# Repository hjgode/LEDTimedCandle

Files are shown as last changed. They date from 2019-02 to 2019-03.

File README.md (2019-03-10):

# LEDTimedCandle

I did a lot of research on battery powered LED candle lights circuits and code and was unable to find a time controlled LED candle light.

As I have some ATTiny13 left, I decided to use this little chip. As I want the LED to do a candle light for about 4hours and then stay of for another 20 hours, I need on timer and counter. Another timer/PWM is needed to immitate a candle flickering. But the ATTiny13 has only one timer. On the ATTiny13 you can either use the timer or PWM.

Fortunately the ATTiny has also a Watchdog timer that can be used to call an interrupt function. The watchdog runs with a separate 128kHz clock, independent from the CPU clock. The largest timeout is 8 seconds. So I need to count this 450 times to have one hour.

Update:
The 128KHz Oscillator for wdt is in real a 131072Hz oscillator (mixing k=1000 and k=1024!).
The ATTiny13A Data sheet says wdt osc will run at 113000Hz at 2V/20°C:

    1024k cycles are 1048576 cycles
    so:
    113000 / 1048576 = 0.1077 => 9.285 seconds
    131072 / 1048576 = 0.125  => 8     seconds
    for one hour we get:
    450*8    = 3600    = 60    minutes
    450*9.285= 4178.27 = 69.63 minutes
    the error cumulates to
    4h 60*4    = 240 
       69.63*4 = 278.55
    diff is 38.55 minutes! in 4 hours
    for 24 hours:
    24h @ 8seconds = 1440
        @ 9.285sec = 1671.12
    diff is 231 minutes for a day! this is 3.85 hours (3h51m) a day!

Instead of theoratic 450 cycles of 8seconds for an hour:
    60*60/9.285=387.72
I now use 388 cycles.

The code makes the ATTiny13 sleep for another 8 seconds or light the LED. The ON phase is 4 hours and the sleep phase will be extended to 20 hours. The sequence starts with the ON phase, when power is applied. In the ON phase I measure about 3mA and in the OFF phase the circuit needs 3µA (without my ISP programmer attached :-).

The circuit is documented in the Arduino code file. Running the ATTiny13 at lower clock than 9.6MHz did not change the power usage. But I switched to the 1.2MHz internal clock and disabled BOD (auto power down for low power) to get a longer runtime with two or three AA batteries.

# References:
* 8.4 Watchdog timer, page 38 ->says 128kHz but means 131072 Hz (kilo for Hertz is 1000 and not 1024 normally)
* watchdog timer prescaler table 8-2, page 43
* Figure 19-65. 128 kHz Watchdog Oscillator Frequency vs. VCC, page 157 ->shows wdt frequency from 105000 to 115000, where is the 128kHz (131072Hz)?

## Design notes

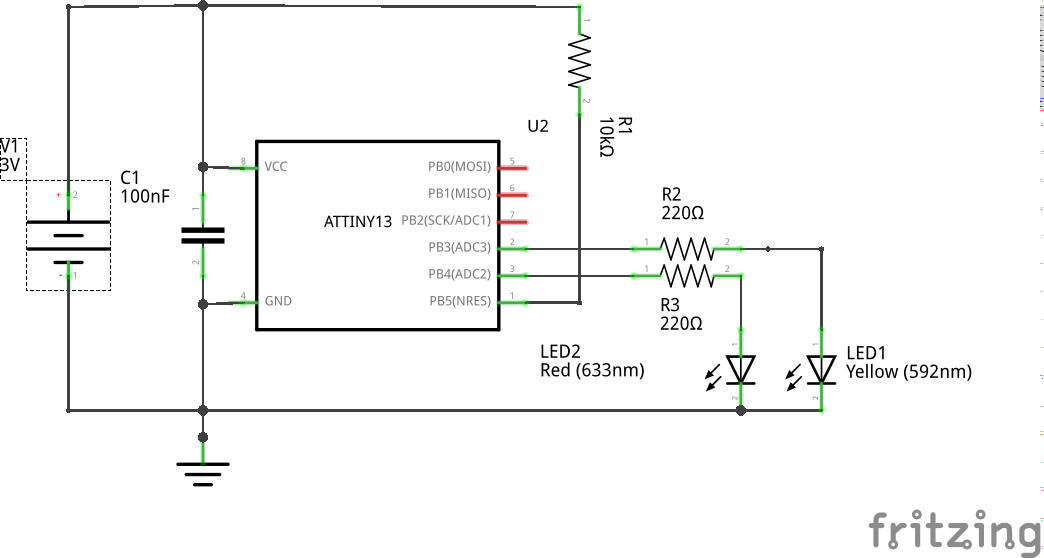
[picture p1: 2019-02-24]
doc/LEDTimedCandle_schem.png

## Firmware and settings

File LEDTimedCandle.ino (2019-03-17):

//use for debug to speed up cycles
//#define MY_DEBUG

//you may need to disable millis in packages/MicroCore/hardware/avr/1.0.4/cores/microcore/core_settings.h

//default 9.6MHz / 8 = 1200000 or at 4.8MHz / 8 = 600000
//use 1.2MHz then 150000, 1200000L
#ifndef F_CPU
	#define F_CPU 1200000L
#endif

// ATtiny13 candle with long sleep mode, wake watchdog timer
// microCore: https://github.com/MCUdude/MicroCore
// Date: 12 October 2013

// http://forum.arduino.cc/index.php?topic=200590.0
// https://electronics.stackexchange.com/questions/74840/use-avr-watchdog-like-normal-isr

// ATMEL ATTINY 13 / ARDUINO
//
// ######### NOTES ########
// disable BOD
// set CPU clock to 1.2MHz should run OK with 1.8V
// ########################

//                      +-\/-+
// RST Ain0 (D 5) PB5  1|    |8  Vcc
//     Ain3 (D 3) PB3  2|    |7  PB2 (D 2) Ain1 SCK
//     Ain2 (D 4) PB4  3|    |6  PB1 (D 1) pwm1 MISO
//                GND  4|    |5  PB0 (D 0) pwm0 MOSI
//                      +----+

//                  +-------------+--o VCC
//                  |             |
//    47k          | |            |    
//                 | |            |
//                  |   +-\/-+    |
//             LED  +--1|    |8---+
//    LED    +--|<-----2|    |7   |                
//           |         3|    |6   |
//    100   | |    +---4|    |5   |
//          | |    |    +----+   ===
//           |     |             === 220pF
//           |     |              |
//          ---   ---            ---
//
// option: add LED on pin 3 (PB4) for heart beat every WDT interrupt

/* ISP 6pol
              +--------+
      MISO    |  o  o  |    VTG (VCC)
              ++       |
      SCK      | o  o  |    MOSI
              ++       |
      RST     |  o  o  |    GND
              +--------+
*/

#include <avr/interrupt.h>
#include <avr/sleep.h>    // Sleep Modes
#include <avr/power.h>    // Power management
#include <avr/wdt.h>      // Watchdog timer
#include <avr/io.h>
#include <util/delay.h>

#ifdef USE_I2C
    #include "./i2c/i2c.h"
#endif
#ifdef USE_I2CMASTER
    #include "./i2cmaster/i2cmaster.h"
#endif

#ifndef WDIF
  #define WDIF WDTIF
#endif
#ifndef WDIE
  #define WDIE WDTIE
#endif
#ifndef bit
    #define bit(b) (1UL << (b))
    //#define _BV(b) (1UL << (b))
#endif

#define USE_HEART_BEAT_LED

//for 8seconds 450 times will be one hour
//but in real we have 113000Hz instead of 131072, the time drifts 3h51m for a day!
//we have two intervals: on-time=4hours; off-time=20 hours
volatile uint16_t sec8_counter=0;
#ifndef MY_DEBUG
  //450x8 = 3600 seconds = 60 minutes
  #define HOUR_INTERVAL 388
  //450
  #define MAX_OFF_HOURS 20
  #define MAX_ON_HOURS 4
#else
  //DEBUG: 1x8 = 8 seconds : ON time = 8x2, OFF time=8*2 seconds
  #define HOUR_INTERVAL 1
  #define MAX_OFF_HOURS 2
  #define MAX_ON_HOURS 2
#endif
volatile uint8_t  on_hours=0;

volatile uint8_t  off_hours=0;
volatile uint8_t bLedIsOn=1; //we start in ON mode

#define LED 3 //;  // pin 2, PB3
#ifdef USE_HEART_BEAT_LED
#define LED2 4 //; // pin 3 for heart beat LED, PB4
#endif

//for candle simulation via pwm
uint8_t PWM_CTR=0;    // 4 bit-Counter
uint8_t FRAME_CTR=0;  // 5 bit-Counter

uint8_t PWM_VAL=0;    // 4 bit-Register
uint8_t NEXTBRIGHT=0; // 4 bit-Register
uint8_t RAND=0;     // 5 bit Signal
uint8_t randflag=0;   // 1 bit Signal

/*
  32 Bit maximum length LFSR
  see http://www.ece.cmu.edu/~koopman/lfsr/index.html
  
  Using inverted values so the LFSR also works with zero initialisiation.
  
*/
uint8_t Rand(void) {
  static uint32_t Z;
  
    if (Z & 1)  { Z = (Z >> 1); }
    else        { Z = (Z >> 1) ^ 0x7FFFF159; }
  
  return (uint8_t)Z;
}

// watchdog interrupt
ISR (WDT_vect)
{
  sec8_counter++;

#ifdef USE_HEART_BEAT_LED  
  //flash heart beat LED
  //turns B0 HIGH
  PORTB |=(1<<LED2);//  digitalWrite(LED2, HIGH);
  _delay_ms(1);
  //turns LED2 LOW
  PORTB &= ~(1 << LED2);//  digitalWrite(LED2, LOW);
#endif
  
  if(sec8_counter>=HOUR_INTERVAL){
    sec8_counter=0;
    if(bLedIsOn==1){
      on_hours++;
      if(on_hours>=MAX_ON_HOURS){
        bLedIsOn=0; //switch to OFF mode
        off_hours=0;
      }
    }else{
      off_hours++;
      if(off_hours>=MAX_OFF_HOURS){
        bLedIsOn=1; //switch to ON mode
        on_hours=0;
      }
    }
  }
  wdt_reset();
}  // end of WDT_vect

void resetWatchdog (void)
{
  // clear various "reset" flags
  MCUSR = 0;    
  // allow changes, disable reset, clear existing interrupt
  WDTCR = bit (WDCE) | bit (WDE) | bit (WDIF);
  // set interrupt mode and an interval (WDE must be changed from 1 to 0 here)
  ///WDTCR = bit (WDIE) | bit (WDP2) | bit (WDP1) | bit (WDP0);    // set WDIE, and 2 seconds delay
#ifdef MY_DEBUG
  WDTCR = bit (WDIE) | bit (WDP2) | bit (WDP1);    // set WDIE, and 1 seconds delay
#else
  WDTCR = bit (WDIE) | bit (WDP3) | bit (WDP0);    // set WDIE, and 8 seconds delay
#endif
  // pat the dog
  wdt_reset();  
}  // end of resetWatchdog
 

 
void goToSleep(void)
{
  set_sleep_mode (SLEEP_MODE_PWR_DOWN);
  ADCSRA = 0;            // turn off ADC
  power_all_disable ();  // power off ADC, Timer 0 and 1, serial interface
  //set all unused ports to output, uses another 8 bytes
/*  
  pinMode(0, OUTPUT);
  pinMode(1, OUTPUT);
  pinMode(2, OUTPUT);
  PORTB = 0b000000; //all low
*/
  cli(); //noInterrupts ();       // timed sequence coming up
  resetWatchdog ();      // get watchdog ready
  sleep_enable ();       // ready to sleep
  sei(); //interrupts ();         // interrupts are required now
  sleep_cpu ();        // sleep                
  sleep_disable ();      // precaution
  power_all_enable();//power_all_enable ();   // power everything back on
}  // end of goToSleep



//mimic candle: https://github.com/cpldcpu/CandleLEDhack/blob/master/Emulator/CandeflickerLED.c
void doCandle(void)
{
if(F_CPU==150000){
  _delay_us(1e6/440/16);
}
if(F_CPU==1200000L){
  _delay_us(1e6/440/16*8);   // Main clock=440*16 Hz
}
  // PWM    
  PWM_CTR++;
  PWM_CTR&=0xf;   // only 4 bit
  
  if (PWM_CTR<=PWM_VAL) {
      //turns B0 HIGH
     PORTB |=(1<<LED);//digitalWrite (LED, HIGH);
  } else {
    //turns B3 LOW
    PORTB &= ~(1 << LED);//digitalWrite (LED, LOW);
  }
  // FRAME
  if (PWM_CTR==0) 
  {
    FRAME_CTR++;
    FRAME_CTR&=0x1f;
    
    if ((FRAME_CTR&0x07)==0)  // generate a new random number every 8 cycles. In reality this is most likely bit serial
    {
      RAND=Rand()&0x1f;
      randflag=((RAND&0x0c)!=0); //optimized, saves 14 bytes!         
/*      if ((RAND&0x0c)!=0) 
        randflag=1; 
      else 
        randflag=0;// only update if valid         
*/    
    }
    // NEW FRAME            
    if (FRAME_CTR==0)
    {
      PWM_VAL=NEXTBRIGHT; // reload PWM
      randflag=1;       // force update at beginning of frame
    }         
    
    if (randflag)
    {
      NEXTBRIGHT=RAND>15?15:RAND;   
    }
  }
}//end doCandle

void setup (void)
{
  resetWatchdog ();  // do this first in case WDT fires

  CLKPR=_BV(CLKPCE);
  CLKPR=0;      // Set clk division factor to 1
  
  //Set PORTB to all outputs
  DDRB = 0xFF;
/*
  pinMode (LED, OUTPUT);
  #ifdef USE_HEART_BEAT_LED
  pinMode (LED2, OUTPUT);
*/

  //turns B0 HIGH
  //PORTB |=(1<<0);
  //turns B3 LOW
  PORTB &= ~(1 << LED);
#ifdef USE_HEART_BEAT_LED
  //turns B4 LOW
  PORTB &= ~(1 << LED2);//  digitalWrite(LED2, LOW);
  #endif
  //disable BOD
//  MCUCR |= _BV(BODS) | _BV(BODSE);
#ifdef USE_I2C
    I2C_Init(); //i2c.h
#endif
#ifdef USE_I2CMASTER
    i2c_init(); //i2cmasher.h
#endif
}  // end of setup

void loop (void)
{
  //sleep 20 hours and work 4 hours
  cli(); //noInterrupts();
  if(bLedIsOn==1){
    doCandle();
  }else{
    //turns B3 LOW
    PORTB &= ~(1 << LED);
    //digitalWrite (LED, LOW); //ensure LED is OFF
   goToSleep ();
  }
  sei(); //interrupts();
}  // end of loop

int main(void){
    setup();
    while(1) {
        loop();
    }
    return 0;
}

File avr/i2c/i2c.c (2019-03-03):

#include <avr/io.h>
#include <util/delay.h>

// Port for the I2C
#define I2C_DDR DDRB
#define I2C_PIN PINB
#define I2C_PORT PORTB

// Pins to be used in the bit banging
#define I2C_CLK 0
#define I2C_DAT 1

/*
#define I2C_DATA_HI()\
I2C_DDR &= ~ (1 << I2C_DAT);\
I2C_PORT |= (1 << I2C_DAT);
#define I2C_DATA_LO()\
I2C_DDR |= (1 << I2C_DAT);\
I2C_PORT &= ~ (1 << I2C_DAT);

#define I2C_CLOCK_HI()\
I2C_DDR &= ~ (1 << I2C_CLK);\
I2C_PORT |= (1 << I2C_CLK);
#define I2C_CLOCK_LO()\
I2C_DDR |= (1 << I2C_CLK);\
I2C_PORT &= ~ (1 << I2C_CLK);
*/

#define I2C_DATA_HI() I2C_DDR&=~(1<<I2C_DAT);
#define I2C_DATA_LO() I2C_DDR|=(1<<I2C_DAT);
#define I2C_CLOCK_HI() I2C_DDR&=~(1<<I2C_CLK);
#define I2C_CLOCK_LO() I2C_DDR|=(1<<I2C_CLK);

void I2C_WriteBit(unsigned char c)
{
    if (c > 0)
    {
        I2C_DATA_HI();
    }
    else
    {
        I2C_DATA_LO();
    }

    I2C_CLOCK_HI();
    _delay_ms(1);

    I2C_CLOCK_LO();
    _delay_ms(1);

    if (c > 0)
    {
        I2C_DATA_LO();
    }

    _delay_ms(1);
}

unsigned char I2C_ReadBit()
{
    I2C_DATA_HI();

    I2C_CLOCK_HI();
    _delay_ms(1);

    unsigned char c = I2C_PIN;

    I2C_CLOCK_LO();
    _delay_ms(1);

    return (c >> I2C_DAT) & 1;
}

// Inits bitbanging port, must be called before using the functions below
//
void I2C_Init()
{
//I2C_DDR &= ~((1<<I2C_CLK)|(1<<I2C_DAT)); //bus pulled hi by pullup resistor.
I2C_PORT &= ~((1<<I2C_CLK)|(1<<I2C_DAT)); // lo when output, HI-Z when input. NEVER CHANGE THIS.

//    I2C_PORT &= ~ ((1 << I2C_DAT) | (1 << I2C_CLK));

    I2C_CLOCK_HI();
    I2C_DATA_HI();

    _delay_ms(1);
}

// Send a START Condition
//
void I2C_Start()
{
    // set both to high at the same time
I2C_DDR &= ~((1<<I2C_CLK)|(1<<I2C_DAT)); //bus pulled hi by pullup resistor.
//I2C_PORT &= ~((1<<I2C_CLK)|(1<<I2C_DAT)); // lo when output, HI-Z when input. NEVER CHANGE THIS.

//    I2C_DDR &= ~ ((1 << I2C_DAT) | (1 << I2C_CLK));
    _delay_ms(1);

    I2C_DATA_LO();
    _delay_ms(1);

    I2C_CLOCK_LO();
    _delay_ms(1);
}

// Send a STOP Condition
//
void I2C_Stop()
{
    I2C_CLOCK_HI();
    _delay_ms(1);

    I2C_DATA_HI();
    _delay_ms(1);
}

// write a byte to the I2C slave device
//
unsigned char I2C_Write(unsigned char c)
{
    for (char i = 0; i < 8; i++)
    {
        I2C_WriteBit(c & 128);

        c <<= 1;
    }

    //return I2C_ReadBit();
    return 0;
}


// read a byte from the I2C slave device
//
unsigned char I2C_Read(unsigned char ack)
{
    unsigned char res = 0;

    for (char i = 0; i < 8; i++)
    {
        res <<= 1;
        res |= I2C_ReadBit();
    }

    if (ack > 0)
    {
        I2C_WriteBit(0);
    }
    else
    {
        I2C_WriteBit(1);
    }

    _delay_ms(1);

    return res;
}

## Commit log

2019-02-24 added doc
    [LEDTimedCandle.fzz]
2019-03-03 about adding i2c software
2019-03-03 now use Makefile i2c or i2cmaster
2019-03-03 added LEDTimedCandle.ino
